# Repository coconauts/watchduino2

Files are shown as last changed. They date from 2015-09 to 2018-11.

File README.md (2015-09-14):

# WatchDuino2

WatchDuino2 is an open hardware project, and an attempt to build a smartwatch
at the reach of everyone: inexpensive and open. So that anyone can afford one,
or even build it from scratch. And at the same time,
so that anyone can built their custom applications for it.

This project is currently a work in progress in a very alpha state,
so expect drastic changes without warning!

See official project page for more info and updates on development:
https://www.coconauts.net/projects/watchduino2/

## Tutorials

- [How to make](docs/how_to_make.md), how to build your own WatchDuino.

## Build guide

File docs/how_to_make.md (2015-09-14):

# How to make a WatchDuino 2

## Bill of materials

You'll need the following in order to build a WatchDuino 2:

- 1 × Arduino mini pro 2 8Mhz 3.3v
- 1 × LIPO battery 240mah
- 1 × 0.96” I2C 128X64 OLED
- 4 × 3x6x2.5mm Push Button 2 Pin
- 1 × 0.06A Flat Micro Vibrator Motor
- 1 × TP4056 Micro USB LIPO charger (5V, 1A) External charger
- 1 × HM-10 Bluetooth 4.0 Uart Transceiver
- 1 × 12mm piezo buzzer speaker
- 1 × Micro USB LIPO charger External charger (optional)

See [this post](https://hackaday.io/project/7244-watchduino2/log/24863-watchduino-2-components-shopping-list)
for a handy shopping list, with links to the products on Aliexpress.

Since the componenents are really cheap (altogether they total roughly 10USD if
bought on Aliexpress), it's probably is a good idea to stock yourself with
at least a couple duplicates of each. Sometimes you can break them while
soldering!

## Loading the WatchDuino firmware in the Arduino Mini

Before you even start building, it is convenient to load the WatchDuino
firmware into the Arduino Mini. You can also do this at the end, but if you do
it now you'll be able to try the components as you go along.

These are the steps you need to follow:

1. To install the firmware on a device you'll need the Arduino SDK and IDE.
You can download the latest bundle for your platform
[on the official website](https://www.arduino.cc/en/Main/Software),
for free. Unzip the package to any location of your choice. Remember this
location, because this will be the `Arduino SDK`, everytime we refer to it.
Open the `arduino` executable inside the SDK folder to run the IDE.

2. Copy all the folders inside the `libraries` folder in this repo into the
`libraries` folder of your Arduino SDK. These are dependencies the WatchDuino
code needs to compile.

3. On the Arduino IDE, click on `File->Open`. Navigate to where you cloned
the WatchDuino repository, and pick the `watch/watch.ino` file to open.
All of the WatchDuino files should now have been loaded in the IDE.

4. On the IDE now go to `Tools->Board` and pick `Arduino Pro or Pro Mini`.
Then pick `Processor:ATMega328 (3.3V, 8Mhz)`. This step is needed because the
IDE needs to know the microcontroller that we are using, in order to apply
the correct compilation options.

5. After all this, you should be able to compile the code. On the IDE, click
on the `Verify` button (the first icon in the toolbar, showing a tick). After a
minute it should be done without errors.

6. You are ready now to upload the code into your Arduino Mini. Plug the TTL
adapter module to your Arduino, and then connect it to your PC via USB.
Some LEDS on the Arduino should turn on.

7. Then go to `Tools->Port`, and you should
be able to see something in there (in my case it's '/dev/ttyUSB0', but this
will likely be different depending on your OS. It's essentially an identifier
for your USB port where your Arduino is plugged). If you see `Tools->Port`
greyed out, it's because you are not running the IDE with sufficient
permissions. If you are on Linux try running the program with a superuser
(eg. `sudo` on Ubuntu).

8. After that, click on the `Upload` button (the second icon in the toolbar,
showing a right pointing arrow). The Arduino Mini should now be loaded with
the WatchDuino firmware.

## Mounting a prototype on a breadboard

Before you go and build the real thing, it's advisable that you build a
prototype version on a breadboard. This way you can test that the code
is correctly loaded into the Arduino board, and that you understood
all the connections in the schematic right.

The schematic can be found in [the `schema` folder of this repo](../schema),
you should see an `.fzz` file in there. You can use the
[Fritzing software](http://fritzing.org/download/?donation=0) to open this
file, and it'll show you a detailed view of the components connected together,
which you can zoom and hightlight the connections in.

After you've successfully flashed the Arduino with the firmware, leave it
connected to the USB, and place it on the breadboard. Then:

- Place the buzzer (on pins D12, and GND). You should hear a "beep" if you
  reset the Arduino.
- Place the screen (pins A4, A5, GND, VCC). You should see the WatchDuino
  interface if you reset the Arduino.
- Place the buttons (pins D2, D4, D5, D6). You should be able to use them
  to navigate through the menus.
- Place the bluetooth module (pins D9, D10, VCC and GND). If your bluetooth
  module has any leds, you should see one of them blinking intermitently.
  This is because it hasn't been paired yet. If you pair to the companion
  phone app it should become fixed.

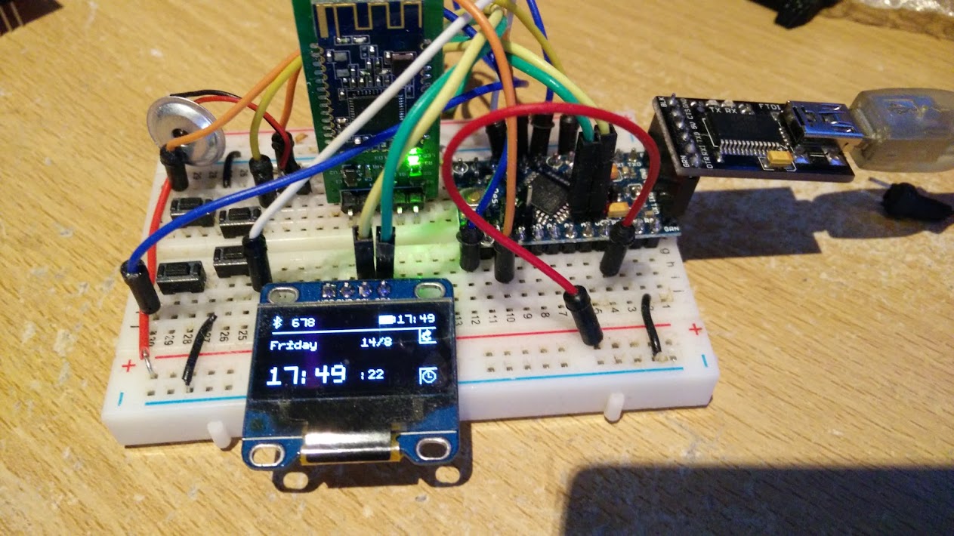
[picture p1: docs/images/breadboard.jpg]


At this point, you have a fully functional (albeit not wearable) WatchDuino.
Have a test around the interface, install the companion app on your phone,
pair the two and check that the bluetooth connection works smoothly.
Refer to [the comapanion app repo](https://github.com/coconauts/watchduino2-companion-app)
for instructions on how to get it.

## Soldering a wearable version

Note: Before you assemble all these modules, it's highly recommended to test
them separately (for instance, by building the breadboard prototype first).

We'll show you how to solder the components together so that they can
fit into the [WatchDuino case](https://www.tinkercad.com/things/0enU2XIDTaP)
we've designed. You can 3D print the case yourself, or using any on-demand
3D printing service, such as [Shapeways](http://www.shapeways.com/).

What you'll need:

- All of the WatchDuino 2 components
- WatchDuino 2 case
- Soldering gun
- Glue gun
- Stripboard

### Solder BLE and Arduino Mini together

For a space-efficient filt, solder the BLE module directly to the back of the
Arduino. You only need 4 pins here:

BLE  | Arduino
---- | -------
TX   | D11
RX   | D10
VCC  | 3.3
GND  | GND

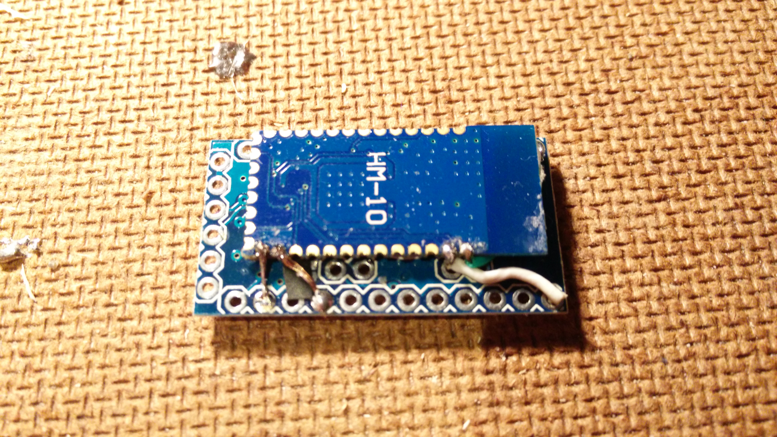
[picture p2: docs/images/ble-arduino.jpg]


## Glue the microbuttons to the screen

We need the buttons to be next to the screen. The easiest way to achieve this
is actually to glue them in place first, and then solder them.

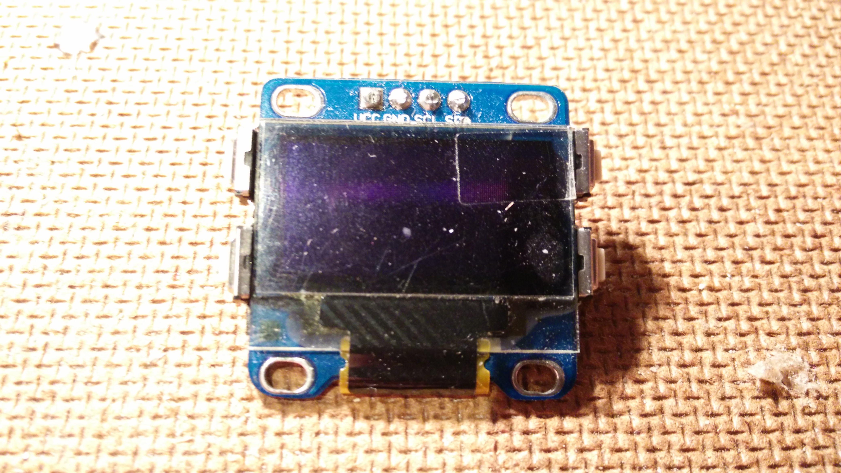
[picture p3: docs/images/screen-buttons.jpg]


### Solder the pins and the screen

The goal now is to connect the Arduino+BLE to the Screen+Buttons.

To make this job easier, we soldered the screen and button pins to a
middle PCB board, made from a coutout from a standard stripboard.

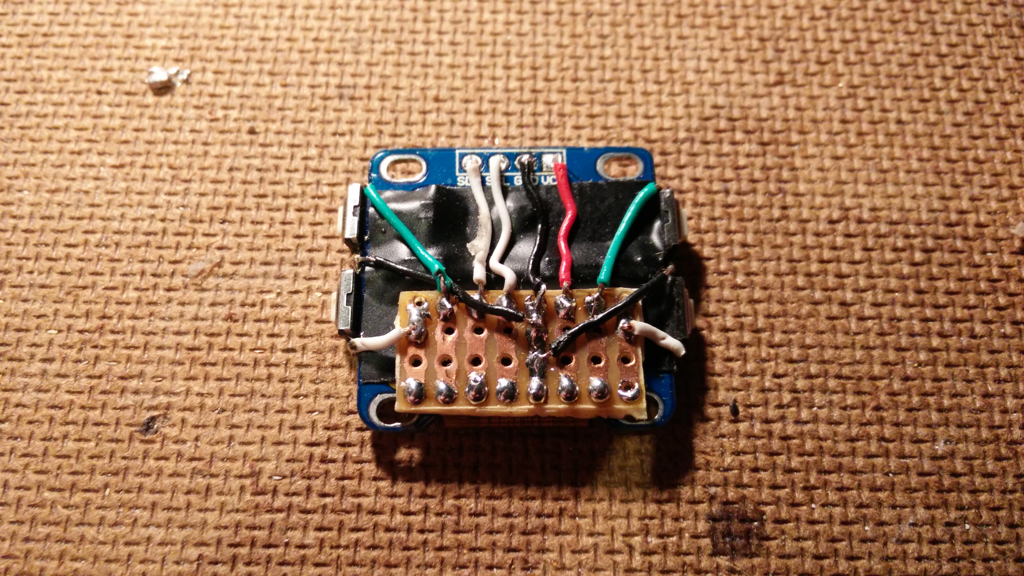
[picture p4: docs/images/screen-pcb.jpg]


Screenboard  | Arduino
------------ | -------
SCL          | A5
SDA          | A4
VCC          | 3.3
GND          | GND
RIGHT BT     | D4
LEFT BT      | D5
SELECT BT    | D6
MENU BT      | D2

Reminder: The screen uses 2 analog pins (A4 and A5) which are in the middle of
the Arduino Mini board.

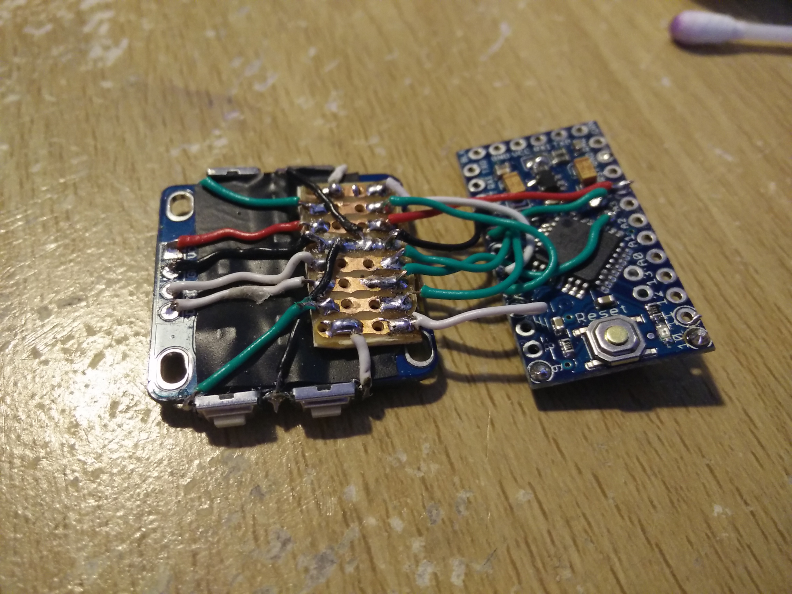
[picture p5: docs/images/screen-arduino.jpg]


Place the components on their place in the strap before soldering, so that
you know they will fit afterwards. Once you finished, you can test the
prototype by connecting the Arduino Mini to your computer (by using the
USB-TTL adaptor).

### Buzzer and Vibrator

Connect these two additional pieces to the following pins:

components  | Arduino
----------- | -------
BUZZER      | D11
VIBRATOR    | D12

They fit into their own link in the strap.

### Battery and changer

Having a rechargeable battery is what will actually make your WatchDuino
portable. For ours we use a 240mAh battery, and a USB LiPo charcher,
both connected to the VCC and GND pins on the Arduino. Each of them
placed on a separate link on the strap.

Optionally, you could remove the LiPo charger from the model, and keep 2 pins
to charge the battery using an external LiPo charger
(and sell it separately to become a millionarie, like the cool companies do).

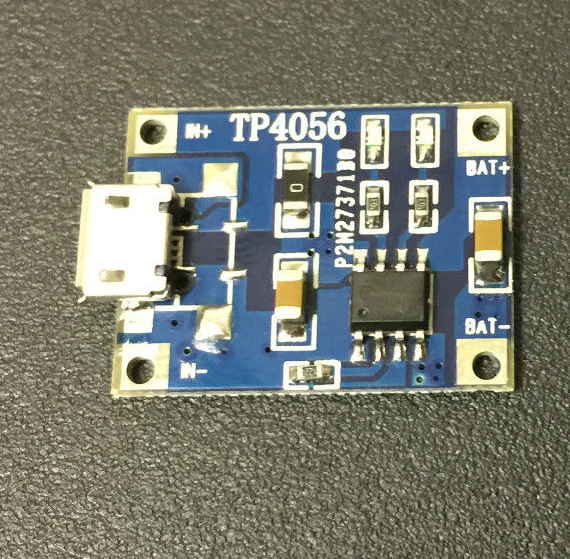
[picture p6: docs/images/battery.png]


### Enjoy your WatchDuino 2

Now you have a fully assembled WatchDuino 2! Place everything in their place
in the case, put it on your wrist, and go have fun with it.

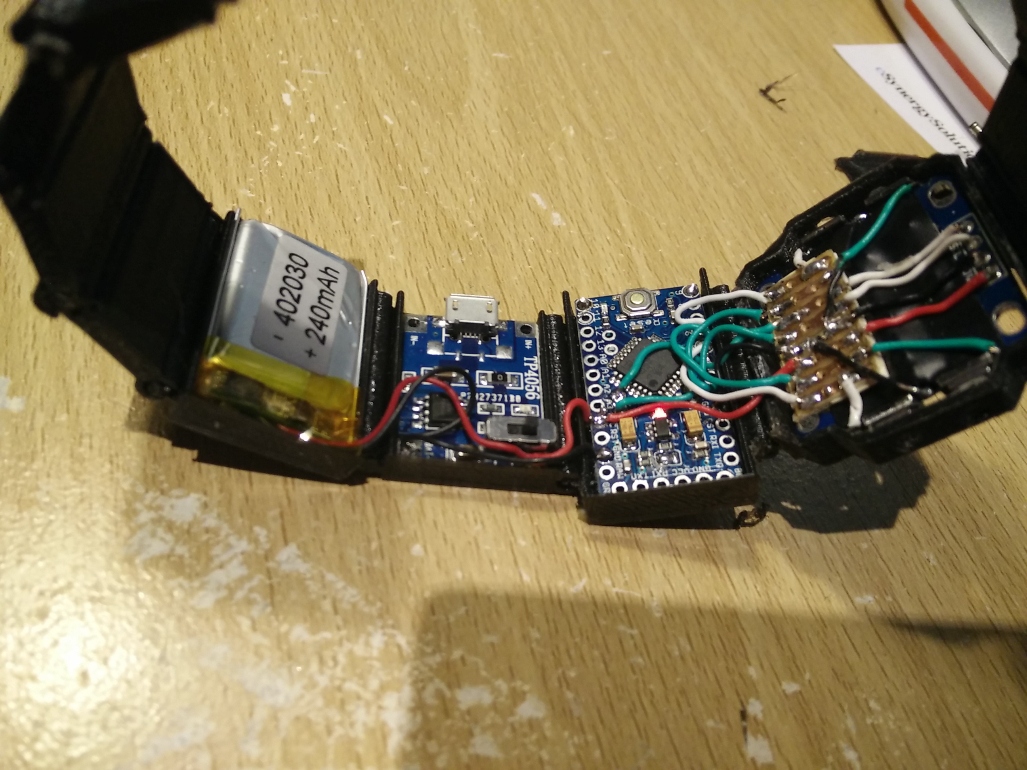
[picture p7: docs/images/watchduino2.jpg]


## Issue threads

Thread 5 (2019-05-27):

I am not able to compile the code

abishekraspberry, 2019-05-27:
Arduino: 1.8.9 (Windows 10), Board: "Arduino Pro or Pro Mini, ATmega328P (3.3V, 8 MHz)"

In file included from sketch\watchcore.h:109:0,

                 from sketch\watchcore.cpp:4:

sketch\bluetooth.h: In member function 'void Bluetooth::processMessage()':

bluetooth.h:147:31: error: 'setTime' was not declared in this scope

         setTime(buffer.toInt());

                               ^

In file included from sketch\alarmSet.h:7:0,

                 from sketch\watchcore.cpp:18:

sketch\drawUtils.h: In function 'void drawTime(int, int, char)':

drawUtils.h:78:23: error: 'hour' was not declared in this scope

   display2digits(hour());

                       ^

drawUtils.h:80:25: error: 'minute' was not declared in this scope

   display2digits(minute());

                         ^

In file included from sketch\watchcore.cpp:19:0:

sketch\watch.h: In member function 'void Watch::drawDigital()':

watch.h:26:27: error: 'day' was not declared in this scope

         display.print(day());

                           ^

watch.h:28:29: error: 'month' was not declared in this scope

         display.print(month());

                             ^

watch.h:34:29: error: 'hour' was not declared in this scope

         display2digits(hour());

                             ^

watch.h:36:31: error: 'minute' was not declared in this scope

         display2digits(minute());

                               ^

watch.h:41:31: error: 'second' was not declared in this scope

         display2digits(second()  );

                               ^

sketch\watch.h: In member function 'void Watch::drawAnalog()':

watch.h:46:27: error: 'day' was not declared in this scope

         display.print(day());

                           ^

watch.h:48:29: error: 'month' was not declared in this scope

         display.print(month());

                             ^

watch.h:53:36: error: 'second' was not declared in this scope

        int r = clock60ToDeg(second());

                                    ^

watch.h:58:32: error: 'minute' was not declared in this scope

        r = clock60ToDeg(minute());

                                ^

watch.h:63:30: error: 'hour' was not declared in this scope

        r = clock12ToDeg(hour());

                              ^

sketch\watch.h: In member function 'virtual void Watch::draw()':

watch.h:73:38: error: 'weekday' was not declared in this scope

         display.print(dayStr(weekday()) );

                                      ^

watch.h:73:39: error: 'dayStr' was not declared in this scope

         display.print(dayStr(weekday()) );

                                       ^

In file included from sketch\watchcore.cpp:26:0:

sketch\topbar.h: In member function 'void Topbar::printBarTime()':

topbar.h:14:22: error: 'second' was not declared in this scope

           if (second() % 2 == 0 ) separator = ':';

                      ^

sketch\watchcore.cpp: In function 'void sysinit()':

watchcore.cpp:142:24: error: 'setTime' was not declared in this scope

     setTime(0,0,0,0,0,0);

                        ^

In file included from sketch\watchcore.h:109:0,

                 from C:\Users\Abishek\Desktop\watchduino2-master\watchduino2-master\watch\watch.ino:13:

sketch\bluetooth.h: In member function 'void Bluetooth::processMessage()':

bluetooth.h:147:31: error: 'setTime' was not declared in this scope

         setTime(buffer.toInt());

                               ^

exit status 1
'setTime' was not declared in this scope

This report would have more information with
"Show verbose output during compilation"
option enabled in File -> Preferences.

I am getting this error. someone please help!!. I have copied the libraries to the library folder. My arduino version is 1.8.9

rephus, 2019-05-27:
Hi, it sounds like you're missing some time related functions. Have you copied all the required libraries specified in our how to make guide ? https://github.com/coconauts/watchduino2/blob/master/docs/how_to_make.md
https://github.com/coconauts/watchduino2/tree/master/libraries . Specially the one called `Time`

abishekraspberry, 2019-05-27:
Yeah i copied all three libraries. If u can tell the arduino version you
used to compile it will be useful. Thanks for your help and faster response.
-Abishek

On Mon, 27 May 2019, 12:54 pm Javier Rengel Jiménez, <
notifications@github.com> wrote:

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

rephus, 2019-05-27:
I have Arduino 1.8.5, gcc 5.4.0 20160609
Try with some Time examples from this page https://playground.arduino.cc/Code/Time/  the methods setTime, hour, minute, weekday... are definetely coming from the `Time` library

abishekraspberry, 2019-05-27:
Yeah i will try thanks

On Mon, 27 May 2019, 1:17 pm Javier Rengel Jiménez, <
notifications@github.com> wrote:

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

abishekraspberry, 2019-05-27:
I have done everything. But now I am getting a new error.

Arduino: 1.8.5 (Windows 10), Board: "Arduino Pro or Pro Mini, ATmega328P
(3.3V, 8 MHz)"
In file included from sketch\watchcore.h:109:0,
                 from
C:\Users\Abishek\Desktop\watchduino2-master\watchduino2-master\watch\watch.ino:13:
sketch\bluetooth.h: In member function 'void Bluetooth::processMessage()':
bluetooth.h:147: error: 'setTime' was not declared in this scope
         setTime(buffer.toInt());
                               ^
exit status 1
'setTime' was not declared in this scope
This report would have more information with
"Show verbose output during compilation"
option enabled in File -> Preferences.

The previous errors have been reduced.
Please help me to proceed further.
thanks

-- Abishek

On Mon, May 27, 2019 at 1:49 PM Abishek Rajagopal <abishekr007@gmail.com>
wrote:

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

stepko2005, 2019-12-15:
Arduino: 1.8.10 (Windows 7), Плата:"Arduino Pro or Pro Mini, ATmega328P (5V, 16 MHz)"

In file included from sketch\watchcore.h:109:0,

                 from sketch\watchcore.cpp:4:

sketch\bluetooth.h: In member function 'void Bluetooth::processMessage()':

bluetooth.h:147:9: error: 'setTime' was not declared in this scope

         setTime(buffer.toInt());

         ^~~~~~~

sketch\bluetooth.h:147:9: note: suggested alternative: 'isotime'

         setTime(buffer.toInt());

         ^~~~~~~

         isotime

In file included from sketch\watchcore.h:109:0,

                 from C:\Users\User\Desktop\watch\watch.ino:13:

sketch\bluetooth.h: In member function 'void Bluetooth::processMessage()':

bluetooth.h:147:9: error: 'setTime' was not declared in this scope

         setTime(buffer.toInt());

         ^~~~~~~

sketch\bluetooth.h:147:9: note: suggested alternative: 'isotime'

         setTime(buffer.toInt());

         ^~~~~~~

         isotime

In file included from sketch\alarmSet.h:7:0,

                 from sketch\watchcore.cpp:18:

sketch\drawUtils.h: In function 'void drawTime(int, int, char)':

drawUtils.h:78:18: error: 'hour' was not declared in this scope

   display2digits(hour());

                  ^~~~

drawUtils.h:80:18: error: 'minute' was not declared in this scope

   display2digits(minute());

                  ^~~~~~

sketch\drawUtils.h:80:18: note: suggested alternative: 'init'

   display2digits(minute());

                  ^~~~~~

                  init

In file included from sketch\watchcore.cpp:19:0:

sketch\watch.h: In member function 'void Watch::drawDigital()':

watch.h:26:23: error: 'day' was not declared in this scope

         display.print(day());

                       ^~~

sketch\watch.h:26:23: note: suggested alternative: 'draw'

         display.print(day());

                       ^~~

                       draw

watch.h:28:23: error: 'month' was not declared in this scope

         display.print(month());

                       ^~~~~

watch.h:34:24: error: 'hour' was not declared in this scope

         display2digits(hour());

                        ^~~~

watch.h:36:24: error: 'minute' was not declared in this scope

         display2digits(minute());

                        ^~~~~~

sketch\watch.h:36:24: note: suggested alternative: 'init'

         display2digits(minute());

                        ^~~~~~

                        init

watch.h:41:24: error: 'second' was not declared in this scope

         display2digits(second()  );

                        ^~~~~~

sketch\watch.h:41:24: note: suggested alternative: 'icon'

         display2digits(second()  );

                        ^~~~~~

                        icon

sketch\watch.h: In member function 'void Watch::drawAnalog()':

watch.h:46:23: error: 'day' was not declared in this scope

         display.print(day());

                       ^~~

sketch\watch.h:46:23: note: suggested alternative: 'draw'

         display.print(day());

                       ^~~

                       draw

watch.h:48:23: error: 'month' was not declared in this scope

         display.print(month());

                       ^~~~~

watch.h:53:29: error: 'second' was not declared in this scope

        int r = clock60ToDeg(second());

                             ^~~~~~

sketch\watch.h:53:29: note: suggested alternative: 'icon'

        int r = clock60ToDeg(second());

                             ^~~~~~

                             icon

watch.h:58:25: error: 'minute' was not declared in this scope

        r = clock60ToDeg(minute());

                         ^~~~~~

sketch\watch.h:58:25: note: suggested alternative: 'init'

        r = clock60ToDeg(minute());

                         ^~~~~~

                         init

watch.h:63:25: error: 'hour' was not declared in this scope

        r = clock12ToDeg(hour());

                         ^~~~

sketch\watch.h: In member function 'virtual void Watch::draw()':

watch.h:73:30: error: 'weekday' was not declared in this scope

         display.print(dayStr(weekday()) );

                              ^~~~~~~

sketch\watch.h:73:30: note: suggested alternative: 'week_date'

         display.print(dayStr(weekday()) );

                              ^~~~~~~

                              week_date

watch.h:73:23: error: 'dayStr' was not declared in this scope

         display.print(dayStr(weekday()) );

                       ^~~~~~

In file included from sketch\watchcore.cpp:26:0:

sketch\topbar.h: In member function 'void Topbar::printBarTime()':

topbar.h:14:15: error: 'second' was not declared in this scope

           if (second() % 2 == 0 ) separator = ':';

               ^~~~~~

sketch\topbar.h:14:15: note: suggested alternative: 'sound'

           if (second() % 2 == 0 ) separator = ':';

               ^~~~~~

               sound

sketch\watchcore.cpp: In function 'void sysinit()':

watchcore.cpp:142:13: error: 'buffer' was not declared in this scope

     fixTime(buffer.toInt());

             ^~~~~~

sketch\watchcore.cpp:142:13: note: suggested alternative: 'buzzer'

     fixTime(buffer.toInt());

             ^~~~~~

             buzzer

watchcore.cpp:142:27: error: 'fixTime' cannot be used as a function

     fixTime(buffer.toInt());

                           ^

Несколько библиотек найдено для "SPI.h"
 Используется: C:\Users\User\Desktop\Arduino\hardware\arduino\avr\libraries\SPI
Несколько библиотек найдено для "U8glib.h"
 Используется: C:\Users\User\Desktop\Arduino\libraries\U8glib
Несколько библиотек найдено для "JeeLib.h"
 Используется: C:\Users\User\Desktop\Arduino\libraries\jeelib-master
Не используется: C:\Users\User\Desktop\Arduino\libraries\jeelib_master
Несколько библиотек найдено для "SoftwareSerial.h"
 Используется: C:\Users\User\Desktop\Arduino\hardware\arduino\avr\libraries\SoftwareSerial
Несколько библиотек найдено для "Wire.h"
 Используется: C:\Users\User\Desktop\Arduino\hardware\arduino\avr\libraries\Wire
exit status 1
'setTime' was not declared in this scope

Этот отчёт будет иметь больше информации с
включенной опцией Файл -> Настройки ->
"Показать подробный вывод во время компиляции"
I don't know what i should do.Help me please.
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

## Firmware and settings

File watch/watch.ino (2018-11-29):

//DEPENDENCIES
#include <Wire.h>
#include <SPI.h>

#include <U8glib.h> // Documentation : https://code.google.com/p/u8glib/wiki/userreference
#include <Time.h> // Source : http://www.pjrc.com/teensy/td_libs_Time.html
                    // Example code : http://playground.arduino.cc//Code/Time?action=sourceblock&num=7
#include <JeeLib.h> // Source: https://github.com/jcw/jeelib
                     // Example code: http://hwstartup.wordpress.com/2013/03/11/how-to-run-an-arduino-on-a-9v-battery-for-weeks-or-months/
                     // powerDown example code: http://hwstartup.wordpress.com/2013/04/15/how-to-run-an-arduino-clone-on-aa-batteries-for-over-a-year-part-2/

#include <SoftwareSerial.h>
#include "watchcore.h"
/*int main(void) {
   init(); // don't forget this!
   sysinit(); 
   
   while (1) sysloop();
}*/

void setup(){
  
      #ifdef DEBUG
      Serial.begin(4800);
      Serial.println(F("Serial ready on 4800, comment DEBUG at watchcore.h to disable"));
    #endif 
    sysinit();
}

void loop(){
      #ifdef DEBUG
      Serial.println(F("loop"));
    #endif 
  sysloop();
}

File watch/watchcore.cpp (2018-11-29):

#include <SoftwareSerial.h>// import the serial library


#include "watchcore.h"

#ifdef JEELIB_ENABLED
  #include <JeeLib.h> 
  ISR(WDT_vect) { Sleepy::watchdogEvent(); }
#endif

#include "notes.h"
#include "images.h"
#include "utils.h"

//Screens
#include "screen.h" //abstract class
#include "settings.h"
#include "alarmSet.h" 
#include "watch.h"
#include "weather.h"
#include "twitter.h"
#include "top10.h"
#include "tfl.h"

//SYSTEM
#include "topbar.h"
#include "selectScreen.h"
#include "notifications.h"
#include "alarmSet.h"

//SLEEP VARIABLES
bool isSleep = false;
long sleepStart = 0;                   // counter
#define AWAKE_TIME 30000 //every 30 seconds
#define SLEEP_TIME 60000
//SOUND VARIABLES

long lastBatMsg = 0;
#define SEND_BAT_TIME 300000 //Send battery status every 5 mins
#define LOW_BAT 3500

long lastTimeUpdate = 0;
#define SEND_UPDATE_TIME 3600000 //Send battery status every hour

short NOTE_DURATION = 1000 / 4; //a quarter
#define DELAY_BETWEEN_NOTES 1000 //ms
#define SECONDS_IN_DAY 86400

//SCREEN VARIABLES
#if defined(SSD1306I2C_U8G)  
  #define OLED_SDA 4
  U8GLIB_SSD1306_128X64 display = U8GLIB_SSD1306_128X64(OLED_SDA);
#endif

int screen = 0; 

//TIMESET
int selectedTimeSet = 0;

//SETTINGS 
bool sleep = true;
bool sound = true;
int selectedSettings = 0;
int fixTime = 0;

boolean alarmEnabled = false;
String weather = "";
unsigned char* weatherImage ;
String response = "";
String notif = "";
boolean warning = false;
Notifications notifications = Notifications();
Alarm alarm = Alarm();

#ifdef BLUETOOTH
  #include <SoftwareSerial.h>// import the serial library
  #define BT_RX 10
  #define BT_TX 9
  SoftwareSerial bluetooth(BT_TX, BT_RX); 
  Bluetooth bt = Bluetooth(); //Bluetooth initialization
#endif

int screensSize = 6 ;
Screen *screens[] = { 
      //new Pong(),
      //new Test(),
      new Watch(),
      new Weather(),
      new Twitter(),
      new Top10(),
      new Tfl(),
      new Settings(),
     /* new TimeSet(),
//    new Snake(),
//    new Pong(),
     ,
      new AlarmSet()*/
};
bool selectScreen = false;
int newScreen = 0;

#ifdef TOPBAR
  Topbar topbar = Topbar();
#endif

#ifdef VIBRATION
  bool vibrationEnabled = true;
  long vibrationStart = 0;
  int vibrationDuration = 0;
  int vibrationTimes =0 ;
  bool vibrationActive = true;
#endif



void sysinit(){
  
    display.setFont(u8g_font_fixed_v0r); //list of availablable fonts https://code.google.com/p/u8glib/wiki/fontsize
    //4x10r //normal
    //4x6r //tiny
    //micro //tiniest
    
    pinMode(WAKE_PIN, INPUT); digitalWrite(WAKE_PIN,HIGH);   // attachInterrupt(0, wakePressed, LOW);
    pinMode(UP_PIN, INPUT); digitalWrite(UP_PIN,HIGH);
    pinMode(DOWN_PIN, INPUT);digitalWrite(DOWN_PIN,HIGH);
    pinMode(SELECT_PIN, INPUT); digitalWrite(SELECT_PIN,HIGH);
        
    #ifdef VIBRATION
      pinMode(VIBRATION,OUTPUT);
    #endif

    bt.sendATCommand("AT");
    bt.sendATCommand("AT+PWRM0");
    bt.sendATCommand("AT+NAMEWatchduino"); 
    bt.sendATCommand("AT+RESET"); 

    //bt.adjustTime();
     
    wakeUp() ;
    vibrate(1,100);
    buzzer();
    setTime(0,0,0,0,0,0);
    
    delay(100); screens[screen]->enter();
   
      
}

void sysloop() {
           
        if (lastBatMsg + SEND_BAT_TIME < millis() ) {
          lastBatMsg = millis();
          bt.send(CM_BAT, readVcc());
        }

        if (lastTimeUpdate + SEND_UPDATE_TIME < millis() ) {
          lastTimeUpdate = millis();
          bt.adjustTime();
        }

        #ifdef BLUETOOTH
            if (bt.enabled){
              bt.update();
              if (bt.receiving) return; //skip delay
            }
        #endif
        
        controller();
        checkSleep();
       
        if( isSleep ) drawSleep();
        else draw();
        
        if (alarmEnabled) {
          alarm.controller();
          alarm.update();
        }
        else if (notifications.hasNotifications() ) notifications.controller();
        else if (selectScreen) selectScreenController();
        else screens[screen]->controller();
        
        screens[screen]->update();
                
         #ifdef VIBRATION
          if (vibrationEnabled && vibrationActive && vibrationStart + vibrationDuration < millis()){
               digitalWrite(VIBRATION, LOW);
               vibrationActive = false;
          }
          
          //Wait between vibrations
          if (vibrationTimes > 1 && !vibrationActive && vibrationStart + vibrationDuration*2 < millis() ) vibrate(vibrationTimes-1, vibrationDuration);
        #endif
     /*
     //TODO enable delay
     if (isAlarmSounding()) customDelay(100); 
        else if (screen < screensSize) customDelay(screens[screen]->getRefresh()); 
        else customDelay(1000);
       */
        //customDelay(500);
       //buzzer(1); 
}

void vibrate(int times, int ms){
  
  #ifdef VIBRATION
    digitalWrite(VIBRATION, HIGH);
    vibrationStart = millis();
    vibrationDuration = ms;
    vibrationTimes = times;
    vibrationActive = true;
  #endif
}

void draw(){
  
    display.firstPage();  
    do {
      
      #ifdef TOPBAR
        topbar.draw();
      #endif    
      
      #ifdef SELECT_SCREEN
        if (selectScreen) drawSelectScreen();
        else {
          if (alarmEnabled) alarm.draw();
          else if (notifications.hasNotifications() )  notifications.draw();
          else screens[screen]->draw();
        }
      #else
      
        if (notifications.hasNotifications() )  notifications.draw();
        else screens[screen]->draw();
      #endif
    } while( display.nextPage() );       
}

boolean lowBattery(){
  return readVcc() < LOW_BAT;
}

void drawSleep(){
  
  display.firstPage();  
  do {
    if (notifications.hasNotifications()) display.drawXBMP(15, 2, message_width,message_height,message_img);
    //if (bt.enabled) display.drawXBMP(0, 0, bluetooth_width,bluetooth_height,bluetooth_img);
    if (lowBattery()) topbar.printBarBattery();
    drawTime(WIDTH/2 - 15,HEIGHT/2, ':');
  } while( display.nextPage() );       
  
}
void customDelay(int ms){
  #ifdef JEELIB_ENABLED
    Sleepy::loseSomeTime(ms); 
  #else
    delay(ms);
  #endif
}
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

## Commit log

2015-08-29 fritzing schematic
    [watchduino2.fzz]
2015-08-30 Initial docs, schematic update
    [watchduino2.fzz]
2015-09-26 Skip empty messages, new weather layout, update time every hour, etc
    [watchcore.cpp, watchcore.h]
2015-10-24 PCB schematic
    [watchduino2-atmega328.fzz]
2018-11-29 Fix blocking Bluetooth AT command on setup
    [watch.ino, watchcore.cpp]
